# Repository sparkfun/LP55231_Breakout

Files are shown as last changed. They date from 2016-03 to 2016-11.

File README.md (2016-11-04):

SparkFun LP55231 LED Driver Breakout
========================================

SparkFun LP55231 LED Driver Breakout

[*SparkFun LP55231 LED Driver Breakout (BOB-13884)*](https://www.sparkfun.com/products/13884)

Breakout Board for the Texas Instruments LP55231 9-channel LED driver IC, with three onboard RGB LEDs.

Repository Contents
-------------------

* **/Documentation** - LP55231 data sheet.
* **/Enclosure** - Enclosure files
* **/Firmware** - Some test sketches.  For more useful sketches, please refer to the [LP55231 Arduino Library](https://github.com/sparkfun/SparkFun_LP55231_Arduino_Library)
* **/Hardware** - Eagle design files (.brd, .sch)
* **/Libraries** - work-in-progress libraries.  Release library has [its own repository](https://github.com/sparkfun/SparkFun_LP55231_Arduino_Library)
* **/Production** - Production panel files (.brd)
* **/Software** - Related software for the <PRODUCT NAME>

Documentation
--------------
* **[Library](https://github.com/sparkfun/SparkFun_LP55231_Arduino_Library)** - Arduino library for the LP55231 breakout board.
* **[Hookup Guide](https://learn.sparkfun.com/tutorials/lp55231-breakout-board-hookup-guide)** - Basic hookup guide for the LP55231 breakout.
* **[SparkFun Fritzing repo](https://github.com/sparkfun/Fritzing_Parts)** - Fritzing diagrams for SparkFun products.
* **[SparkFun 3D Model repo](https://github.com/sparkfun/3D_Models)** - 3D models of SparkFun products.
* **[SparkFun Graphical Datasheets](https://github.com/sparkfun/Graphical_Datasheets)** -Graphical Datasheets for various SparkFun products.

Product Versions
----------------
* [BOB-13884](https://www.sparkfun.com/products/13884)- Storefront page where you can purchase the LP55231 breakout board.

Version History
---------------
* [7303a14bc03e4db13bc608a852c81e9e0ca2a5a7](https://github.com/sparkfun/LP55231_Breakout/commit/7303a14bc03e4db13bc608a852c81e9e0ca2a5a7) - Initial release version.

License Information
-------------------

This product is _**open source**_!

Please review the LICENSE.md file for license information.

If you have any questions or concerns on licensing, please contact techsupport@sparkfun.com.

Distributed as-is; no warranty is given.

- Your friends at SparkFun.

_<COLLABORATION CREDIT>_

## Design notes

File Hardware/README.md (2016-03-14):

SparkFun <PRODUCT NAME> Design Files
=====================================

The .sch and .brd files hare are Eagle CAD schematic and PCB design files from SparkFun Electronics.
A freeware version of Eagle can be found [here](http://www.cadsoftusa.com/download-eagle/freeware/).

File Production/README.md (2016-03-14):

SparkFun <PRODUCT NAME> Production Files
=========================================

These are the production files SparkFun uses for printing PCBs.

License Information
-------------------
This product is open source! 

The hardware is released under [Creative Commons ShareAlike 4.0 International](https://creativecommons.org/licenses/by-sa/4.0/).

Please use, reuse, and modify these files as you see fit. Please maintain attribution to SparkFun Electronics and release anything derivative under the same license.

Distributed as-is; no warranty is given.

- Your friends at SparkFun.

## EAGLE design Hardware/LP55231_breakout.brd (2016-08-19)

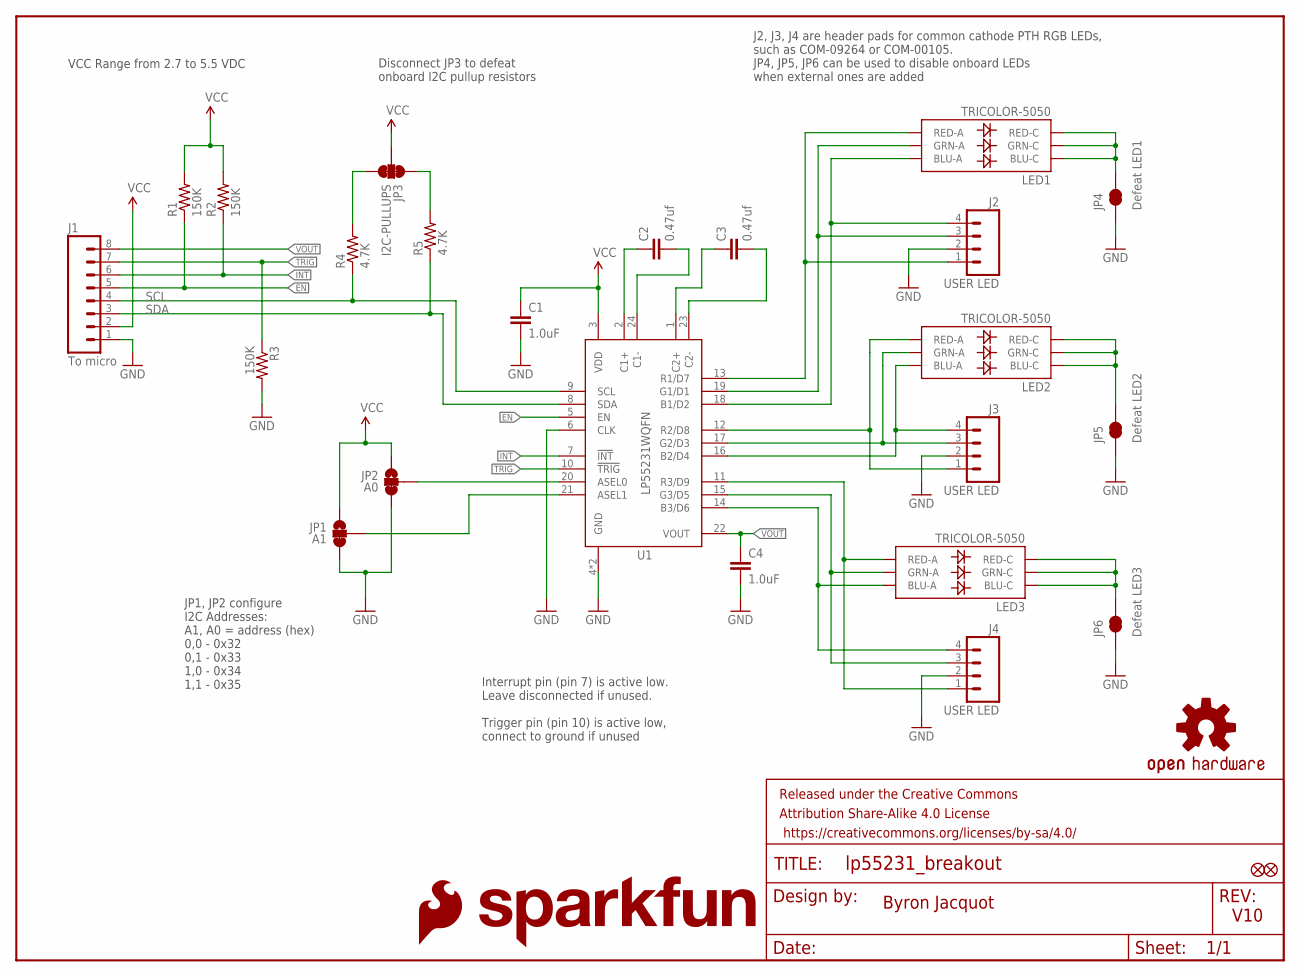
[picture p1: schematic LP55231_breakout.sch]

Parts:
C1, C4: 1.0uF; 0603-CAP
C2, C3: 0.47uf; 0603-CAP
FD1, FD2: FIDUCIALUFIDUCIAL; MICRO-FIDUCIAL
FRAME1: FRAME-LETTER; CREATIVE_COMMONS
J1: To micro; 1X08_NO_SILK
J2, J3, J4: USER LED; 1X04_NO_SILK_ALL_ROUND
JP1: A1; PAD-JUMPER-3-2OF3_NC_BY_TRACE_YES_SILK_FULL_BOX
JP2: A0; PAD-JUMPER-3-2OF3_NC_BY_TRACE_YES_SILK_FULL_BOX
JP3: I2C-PULLUPS; PAD-JUMPER-3-3OF3_NC_BY_TRACE_YES_SILK_FULL_BOX
JP4: Defeat LED1; PAD-JUMPER-2-NC_BY_TRACE_NO_SILK
JP5: Defeat LED2; PAD-JUMPER-2-NC_BY_TRACE_NO_SILK
JP6: Defeat LED3; PAD-JUMPER-2-NC_BY_TRACE_NO_SILK
LED1, LED2, LED3: TRICOLOR-5050; LED-TRICOLOR-5050
LOGO1: SFE_LOGO_FLAME.1_INCH; SFE_LOGO_FLAME_.1
LOGO2: SFE_LOGO_NAME.1_INCH; SFE_LOGO_NAME_.1
LOGO3: OSHW-LOGOS; OSHW-LOGO-S
R1, R2, R3: 150K; 0603-RES
R4, R5: 4.7K; 0603-RES
U1: LP55231WQFN; WQFN-24

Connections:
ADDR0: JP2.2, U1.20 (ASEL0)
ADDR1: JP1.2, U1.21 (ASEL1)
B1: J2.4, LED1.3 (BLU-A), U1.18 (B1/D2)
B2: J3.4, LED2.3 (BLU-A), U1.16 (B2/D4)
B3: J4.4, LED3.3 (BLU-A), U1.14 (B3/D6)
EN: J1.5, R1.1, U1.5 (EN)
G1: J2.3, LED1.1 (GRN-A), U1.19 (G1/D1)
G2: J3.3, LED2.1 (GRN-A), U1.17 (G2/D3)
G3: J4.3, LED3.1 (GRN-A), U1.15 (G3/D5)
GND: C1.2, C4.2, J1.1, J2.2, J3.2, J4.2, JP1.3, JP2.3, JP4.1, JP5.1, JP6.1, R3.2, U1.4 (GND), U1.6 (CLK), U1.EP (GND)
INT: J1.6, R2.1, U1.7 (!INT)
unnamed: JP6.2, LED3.4 (BLU-C), LED3.5 (RED-C), LED3.6 (GRN-C)
unnamed: JP5.2, LED2.4 (BLU-C), LED2.5 (RED-C), LED2.6 (GRN-C)
unnamed: JP4.2, LED1.4 (BLU-C), LED1.5 (RED-C), LED1.6 (GRN-C)
unnamed: C2.1, U1.2 (C1+)
unnamed: C2.2, U1.24 (C1-)
unnamed: C3.1, U1.1 (C2+)
unnamed: C3.2, U1.23 (C2-)
unnamed: JP3.1, R5.2
unnamed: JP3.3, R4.2
R1: J2.1, LED1.2 (RED-A), U1.13 (R1/D7)
R2: J3.1, LED2.2 (RED-A), U1.12 (R2/D8)
R3: J4.1, LED3.2 (RED-A), U1.11 (R3/D9)
SCL: J1.4, R4.1, U1.9 (SCL)
SDA: J1.3, R5.1, U1.8 (SDA)
TRIG: J1.7, R3.1, U1.10 (!TRIG)
VCC: C1.1, J1.2, JP1.1, JP2.1, JP3.2, R1.2, R2.2, U1.3 (VDD)
VOUT: C4.1, J1.8, U1.22 (VOUT)

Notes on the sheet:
Byron Jacquot
V10
VCC Range from 2.7 to 5.5 VDC
JP1, JP2 configure I2C Addresses: A1, A0 = address (hex) 0,0 - 0x32 0,1 - 0x33 1,0 - 0x34 1,1 - 0x35
J2, J3, J4 are header pads for common cathode PTH RGB LEDs, such as COM-09264 or COM-00105. JP4, JP5, JP6 can be used to disable onboard LEDs when external ones are added
Disconnect JP3 to defeat onboard I2C pullup resistors
Interrupt pin (pin 7) is active low. Leave disconnected if unused. Trigger pin (pin 10) is active low, connect to ground if unused

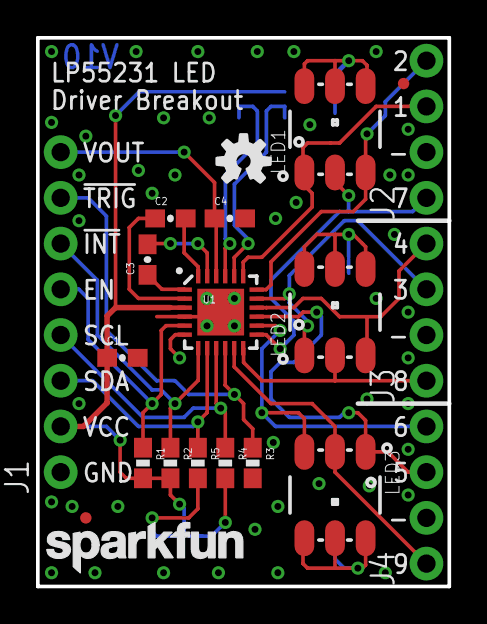
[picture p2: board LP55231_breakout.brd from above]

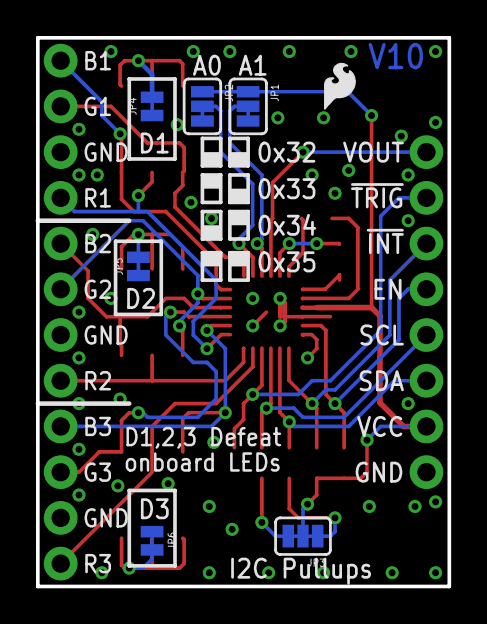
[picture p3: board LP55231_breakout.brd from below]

Board: 4 copper layers, 22.9 x 30.5 mm, 29 parts (7 on the bottom side), 28 nets.

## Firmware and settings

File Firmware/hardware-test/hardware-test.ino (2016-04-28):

#include <Wire.h>

static const int32_t enable_pin = 15; // Apparently active high?
static const int32_t trigger_pin = 14; // low if unused

// register stuff
static const uint8_t REG_CNTRL1 = 0x00;
static const uint8_t REG_CNTRL2 = 0x01;
static const uint8_t REG_RATIO_MSB = 0x02;
static const uint8_t REG_RATIO_LSB = 0x03;
static const uint8_t REG_OUTPUT_ONOFF_MSB = 0x04;
static const uint8_t REG_OUTPUT_ONOFF_LSB = 0x05;

// Per LED control channels - fader channel assig, log dimming enable, temperature compensation
static const uint8_t REG_D1_CTRL = 0x06;
static const uint8_t REG_D2_CTRL = 0x07;
static const uint8_t REG_D3_CTRL = 0x08;
static const uint8_t REG_D4_CTRL = 0x09;
static const uint8_t REG_D5_CTRL = 0x0a;
static const uint8_t REG_D6_CTRL = 0x0b;
static const uint8_t REG_D7_CTRL = 0x0c;
static const uint8_t REG_D8_CTRL = 0x0d;
static const uint8_t REG_D9_CTRL = 0x0e;

// Direct PWM control registers
static const uint8_t REG_D1_PWM  = 0x16;
static const uint8_t REG_D2_PWM  = 0x17;
static const uint8_t REG_D3_PWM  = 0x18;
static const uint8_t REG_D4_PWM  = 0x19;
static const uint8_t REG_D5_PWM  = 0x1a;
static const uint8_t REG_D6_PWM  = 0x1b;
static const uint8_t REG_D7_PWM  = 0x1c;
static const uint8_t REG_D8_PWM  = 0x1d;
static const uint8_t REG_D9_PWM  = 0x1e;

// Drive cuttent registers
static const uint8_t REG_D1_I_CTL = 0x26;
static const uint8_t REG_D2_I_CTL  = 0x27;
static const uint8_t REG_D3_I_CTL  = 0x28;
static const uint8_t REG_D4_I_CTL  = 0x29;
static const uint8_t REG_D5_I_CTL  = 0x2a;
static const uint8_t REG_D6_I_CTL  = 0x2b;
static const uint8_t REG_D7_I_CTL  = 0x2c;
static const uint8_t REG_D8_I_CTL  = 0x2d;
static const uint8_t REG_D9_I_CTL  = 0x2e;

static const uint8_t REG_MISC     = 0x36;
static const uint8_t REG_PC1 = 0x37;
static const uint8_t REG_PC2 = 0x38;
static const uint8_t REG_PC3 = 0x39;
static const uint8_t REG_STATUS_IRQ = 0x3A;
static const uint8_t REG_RESET      = 0x3D;

static const uint8_t REG_PROG1_START = 0x4C;
static const uint8_t REG_PROG2_START = 0x4D;
static const uint8_t REG_PROG3_START = 0x4E;
static const uint8_t REG_PROG_PAGE_SEL = 0x4f;

// Memory is more confusing - there are 4 pages, sel by addr 4f
static const uint8_t REG_PROG_MEM_BASE = 0x50;
//static const uint8_t REG_PROG_MEM_SIZE = 0x;//
static const uint8_t REG_PROG_MEM_END  = 0x6f;

static const uint8_t REG_ENG1_MAP_MSB = 0x70;
static const uint8_t REG_ENG1_MAP_LSB = 0x71;
static const uint8_t REG_ENG2_MAP_MSB = 0x72;
static const uint8_t REG_ENG2_MAP_LSB = 0x73;
static const uint8_t REG_ENG3_MAP_MSB = 0x74;
static const uint8_t REG_ENG3_MAP_LSB = 0x75;

static uint32_t next;
//static bool     ledon;

int8_t readReg(int8_t dev, int8_t reg)
{
  // Wire is awkward because it doesn't really have a register address concept.
  // http://www.arduino.cc/en/Tutorial/SFRRangerReader for reference
  
  Wire.beginTransmission(dev);
  Wire.write(reg);
  Wire.endTransmission();

  if(Wire.requestFrom(dev, 1))
  {
    return(Wire.read());
  }
  else
  {
    Serial.println("readReg failed?");
  }
}

void writeReg(int8_t dev, int8_t reg, int8_t val)
{
  Wire.beginTransmission(dev);
  Wire.write(reg);
  Wire.write(val);
  Wire.endTransmission();
}

void setup()
{
  
  pinMode(enable_pin, OUTPUT);
  digitalWrite(enable_pin, LOW);
  digitalWrite(enable_pin, HIGH);

  // Trigger is active hi, so unused means low
  pinMode(trigger_pin, OUTPUT);
  digitalWrite(trigger_pin, LOW);

  Wire.begin();

  next = millis() + 3000;
}



void loop()
{
  int32_t result;
  int8_t  val;
  static uint32_t count = 0;
  
  if(millis() >= next)
  {
    Serial.print("#");
    Serial.println(count);

    if(count == 0)
    {  
      // enable chip
//      writeReg(0x32, REG_CNTRL1, 0x40 );
//      val = readReg(0x32, REG_CNTRL1);
//      Serial.print("REG_CNTRL1 ");
//      Serial.println(val);

      // force reset
      writeReg(0x32, REG_RESET, 0xff);
      // reenable
      writeReg(0x32, REG_CNTRL1, 0x40 );
      
      val = readReg(0x32, REG_STATUS_IRQ);
      Serial.print("REG_STATUS_IRQ ");
      Serial.println(val);
      
      delay(100);

      val = readReg(0x32, REG_STATUS_IRQ);
      Serial.print("REG_STATUS_IRQ ");
      Serial.println(val);

      // enable internal clock & charge pump
      writeReg(0x32, REG_MISC, 0x1b);
      //writeReg(0x32, REG_MISC, 0x03);
      val = readReg(0x32, REG_MISC);
      Serial.print("REG_MISC ");
      Serial.println(val);

      // enable ratiometric color?
//      writeReg(0x32, REG_RATIO_MSB, 0x01);
//      writeReg(0x32, REG_RATIO_LSB, 0xff);

#if 1 
      // set all outputs to log
      writeReg(0x32, REG_D1_CTRL, 20);
      writeReg(0x32, REG_D2_CTRL, 20);
      writeReg(0x32, REG_D3_CTRL, 20);
      writeReg(0x32, REG_D4_CTRL, 20);
      writeReg(0x32, REG_D5_CTRL, 20);
      writeReg(0x32, REG_D6_CTRL, 20);
      writeReg(0x32, REG_D7_CTRL, 20);
      writeReg(0x32, REG_D8_CTRL, 20);
      writeReg(0x32, REG_D9_CTRL, 20);
#endif


      //Try poking in a program
      //turn on ram access?
      // CNTRL1 has 0's in engine control - IE: hold mode
      writeReg(0x32, REG_CNTRL2, 0x10);

      // the wait to change modes
      do
      {
        val = readReg(0x32, REG_STATUS_IRQ) & 0x10; // engine busy bit
        Serial.print(".");
      }
      while(val);

      //try to write program from example
      // datasheet says MSB of each instruction is in earlier address
      // TBD: could optimize with a sequence of byte writes, using auto increment
      writeReg(0x32, REG_PROG_MEM_BASE     , 0x9c);// 0 output map start at addr _
      writeReg(0x32, REG_PROG_MEM_BASE +  1, 0x06);
      writeReg(0x32, REG_PROG_MEM_BASE +  2, 0x9c );// 1 output map - sel at addr 4
      writeReg(0x32, REG_PROG_MEM_BASE +  3, 0x8e);
      
      writeReg(0x32, REG_PROG_MEM_BASE +  4, 0x0e);// 2 ramp up
      writeReg(0x32, REG_PROG_MEM_BASE +  5, 0xff);
      writeReg(0x32, REG_PROG_MEM_BASE +  6, 0x0f);// 3 ramp dn
      writeReg(0x32, REG_PROG_MEM_BASE +  7, 0xff);
      writeReg(0x32, REG_PROG_MEM_BASE +  8, 0x9d);// 4 next map entry
      writeReg(0x32, REG_PROG_MEM_BASE +  9, 0x80);
      writeReg(0x32, REG_PROG_MEM_BASE +  10, 0xa0);// 5 loop
      writeReg(0x32, REG_PROG_MEM_BASE + 11, 0x02);

      writeReg(0x32, REG_PROG_MEM_BASE + 12, 0x00);// 6 mux data
      writeReg(0x32, REG_PROG_MEM_BASE + 13, 0x01);
      writeReg(0x32, REG_PROG_MEM_BASE + 14, 0x00);// 7 mux data
      writeReg(0x32, REG_PROG_MEM_BASE + 15, 0x02);
      writeReg(0x32, REG_PROG_MEM_BASE + 16, 0x00);// 8 mux data
      writeReg(0x32, REG_PROG_MEM_BASE + 17, 0x04);
      writeReg(0x32, REG_PROG_MEM_BASE + 18, 0x00);// 9 mux data
      writeReg(0x32, REG_PROG_MEM_BASE + 19, 0x08);
      writeReg(0x32, REG_PROG_MEM_BASE + 20, 0x00);// 10mux data
      writeReg(0x32, REG_PROG_MEM_BASE + 21, 0x10);
      writeReg(0x32, REG_PROG_MEM_BASE + 22, 0x00);// 11mux data
      writeReg(0x32, REG_PROG_MEM_BASE + 23, 0x20);
      writeReg(0x32, REG_PROG_MEM_BASE + 24, 0x00);// 12mux data
      writeReg(0x32, REG_PROG_MEM_BASE + 25, 0x40);
      writeReg(0x32, REG_PROG_MEM_BASE + 26, 0x00);// 13mux data
      writeReg(0x32, REG_PROG_MEM_BASE + 27, 0x80);
      writeReg(0x32, REG_PROG_MEM_BASE + 28, 0x01);// 14mux data
      writeReg(0x32, REG_PROG_MEM_BASE + 29, 0x00);

      // and that's amlost a full page...can we put more data in next page??

#if 0
      // check too see if it's there?
      Serial.print("prog peek ");
      Serial.println((readReg(0x32, REG_PROG_MEM_BASE) & 0xff), HEX);
      Serial.println((readReg(0x32, REG_PROG_MEM_BASE+1) & 0xff), HEX);
      Serial.println((readReg(0x32, REG_PROG_MEM_BASE+2) & 0xff), HEX);
      Serial.println((readReg(0x32, REG_PROG_MEM_BASE+3) & 0xff), HEX);
#endif

      // set the PC1
      writeReg(0x32, REG_PC1, 0);
        
      // tell engine how to execute the program...free/step, etc
      writeReg(0x32, REG_CNTRL1, 0x40 | 0x20 );

      // and start execution
      writeReg(0x32, REG_CNTRL2, 0x20);
      
    }

#if 0
    for(uint8_t i = 0; i < 32; i++)
    {
      val = readReg(0x32, i);
      
      Serial.print("Register: ");
      Serial.print( i );
      Serial.print(":");
      Serial.println((val&0x0ff), HEX);
    }

    for(uint8_t i = 0x26; i < 0x2f; i++)
    {
      val = readReg(0x32, i);
      
      Serial.print("Register: ");
      Serial.print( i );
      Serial.print(":");
      Serial.println((val&0x0ff), HEX);
    }
#endif

    val = readReg(0x32, REG_PC1);
    Serial.print("PC1 val ");
    Serial.println(val);
    val = readReg(0x32, REG_ENG1_MAP_LSB);
    Serial.print("map lsbs");
    Serial.println(val);


#if 0
    val = count & 0xff;
    writeReg(0x32, REG_D8_PWM, val );
    writeReg(0x32, REG_D3_PWM, val );
    writeReg(0x32, REG_D4_PWM, val );

    writeReg(0x32, REG_D9_PWM, 0xff-val );
    writeReg(0x32, REG_D5_PWM, 0xff-val );
    writeReg(0x32, REG_D6_PWM, 0xff-val );
//
//    writeReg(0x32, REG_D7_PWM, (count>>1) );
//    writeReg(0x32, REG_D1_PWM, count );
//    writeReg(0x32, REG_D2_PWM, count );


//    val = readReg(0x32, REG_D8_PWM);
//    Serial.print("PWM D8 val ");
//    Serial.println(val);

#endif
    next += 1000;
    count++;
  }
}

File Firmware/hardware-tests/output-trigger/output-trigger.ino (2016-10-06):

#include <lp55231.h>

#include <Wire.h>

//#include "lp55231.h"

static const int32_t enable_pin = 15; // Apparently active high?
static const int32_t trigger_pin = 14; // low if unused
static const int32_t interrupt_pin = 16;


static uint32_t next;
//static bool     ledon;

static lp55231 ledChip(0x32);

/*
 * More trickery at play here (not as tangled as the interrupt example).
 * 
 * The LP55231 trigger line can be used as both an input and an output.
 * This example does exactly that...bit at first,v we couldn't explain why it worked.
 * 
 * The Trigger instruction on the LP allows for it listen for a trigger, or to drive 
 * the trigger line.  If both options are used in the same instruction, it sends a 
 * short (roughly 100 uSec) trigger pulse, then waits for a response.
 * 
 * This sketch waits until it sees that pulse, observes it going high again, then 
 * drives the line.
 * 
 * But it wasn't entirely apparent why & how it was working.  The AVR port pin 
 * architecture held the explanation.
 * 
 * The trigger pin on the pro micro is configured as INPUT_PULLUP in
 * setup().  Loop polls that pin, looking for a low.  When it finds a low, it waits for 
 * it to go high again, waits a touch longer, the drives it low itself.
 * 
 * Yes, it's an input...but it's allowed to drive it low, but somewhat indirectly.
 * 
 * When configured as an output, the data bits enable the pullup resistors.
 * 
 * So by writing a low to the output pin, we essentially defeat the pullup.
 * The Trigger line is pulled low on the LP breakout, which takes over when the 
 * PUP is defeated.
 * 
 * This will probably work with other AVR based microcontrollers, but 
 * might not be portable beynd that.
 */

static const uint16_t program[] =
{
  0x9c09, // 0 map start addr
  0x9c8c, // 1 map end addr
  0x3000, // 2 wait
  0x0eff, // 3 ramp up over 255
  0x3000, // 4 wait
  0x0fff, // 5 ramp down over 255
  0x9d80, // 6 mux map next
  0xf040, // 7 trigger - send to micro, and wait for response.
  0xa002, // 8 loop to 2
  0x01ff, // 9 channel map - all
  0x01c0, // a channel map - reds
  0x0015, // b channel map - greens
  0x002a, // c channel map - blues
};


void setup()
{
  Serial.begin(9600);

  delay(2000);
  Serial.println("### Setup entry");

  pinMode(enable_pin, OUTPUT);
  digitalWrite(enable_pin, LOW);
  digitalWrite(enable_pin, HIGH);

  // Trigger is active hi, so unused means low
  // but External trigger signal is active low
  pinMode(trigger_pin, INPUT_PULLUP);
  //digitalWrite(trigger_pin, HIGH);

  pinMode(interrupt_pin, INPUT);

  ledChip.init();
  ledChip.reset();
  ledChip.enable();

  delay(1000);

  for (uint8_t i = 0; i < 9; i++)
  {
    ledChip.setLogBrightness(i);
    ledChip.setDriveCurrent(i, 111);
  }

#if 1
  if (ledChip.loadProgram(program, 16))
  {
    Serial.println("Program loaded?");
  }
  else
  {
    Serial.println("Program dodn't load?");
  }
#endif

  next = millis() + 3000;

  ledChip.clearInterrupt();
  
  ledChip.setEngineEntryPoint(0, 0);
  ledChip.setEnginePC(0, 0);
  
  ledChip.setEngineModeFree(0);
  ledChip.showControls();

  ledChip.setEngineRunning(0);

  Serial.println("### Setup complete");

}



void loop()
{
  int32_t result;
  int8_t  val;
  static uint32_t count = 1;

  if ( !digitalRead(trigger_pin))
  {
    Serial.println("trigger");

    while (!digitalRead(trigger_pin))
      ;

    delay(5);
    digitalWrite(trigger_pin, LOW);
    delay(5);
    digitalWrite(trigger_pin, HIGH);

  }

  if (millis() >= next)
  {
    Serial.print("#");
    Serial.print(count);

    Serial.print(" PC:");
    Serial.println(ledChip.getEnginePC(0));

    if (count == 1)
    {
      //ledChip.fastProgram(program);
    }

    //    if (count % 4 == 0)
    //    {
    //      Serial.println("send trigger");
    //      digitalWrite(trigger_pin, LOW);
    //      delay(20);
    //      digitalWrite(trigger_pin, HIGH);
    //
    //      Serial.println(ledChip.getEngineMap(0), HEX);
    //
    //    }

    count++;
    next += 1000;

  }
}

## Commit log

2016-03-15 Initial design files.
    Library, schem and PCB, all WIP.
    [LP55231_breakout.brd, LP55231_breakout.sch]
2016-03-24 PCB Work in progress.
    [LP55231_breakout.brd, LP55231_breakout.sch]
2016-03-25 Incremental PCB routing checkin.
    Eagle crashed and I'm paranoid now.
    [LP55231_breakout.brd, LP55231_breakout.sch]
2016-03-25 Routing approaching completion.
    [LP55231_breakout.brd, LP55231_breakout.sch]
2016-03-31 Prepping for review.
    BOM created, checklist scrubbed.
    [LP55231_breakout.brd, LP55231_breakout.sch]
2016-04-04 Straight out of QFN.
    Fewer bends & kinks.
    [LP55231_breakout.brd]
2016-04-04 Fixing review issues.
    -Fiducial moved from under silk.
    -Swapped numbering of LED's 2 & 3.
    [LP55231_breakout.brd, LP55231_breakout.sch]
2016-04-27 Adding a note for I2C r/w info.
2016-05-04 Incremental changes.
    Adding software library features to support hardware testing.
    Trigger and interrupt pins are working.
2016-05-06 Updates to PCB after testing.
    Preparing for second round of prototypes.
    [LP55231_breakout.brd, LP55231_breakout.sch]
2016-05-09 Updates after group review.
    Addressing things in issue #3:
    -bump version number
    -Add silk indicating flooded/empty configuration on A0/A1
    -space out passives on front (check tkeepout)
    -remove extra junction dot between 150k res and Vcc on schematic
    [LP55231_breakout.brd, LP55231_breakout.sch]
2016-05-10 Checklist updates for proto round 2.
    [LP55231_breakout.brd, LP55231_breakout.sch]
2016-05-11 Checklist review issues
    Numbering of jumpers vs. comments got mismatched.
    Now fixed.
    [LP55231_breakout.brd, LP55231_breakout.sch]
2016-06-15 Fixing RGB assignments of first LED.
    [LP55231_breakout.brd, LP55231_breakout.sch]
2016-06-21 Rolling version number
    From V02 to V03.
    [LP55231_breakout.brd, LP55231_breakout.sch]
2016-06-22 Changes post-review.
    "G" becomes "-", to prevent confusion with "6".
    Angle voliation inside LED pad remedied.
    [LP55231_breakout.brd]
2016-06-24 Clarifying one schematic note.
    [LP55231_breakout.sch]
2016-08-05 Adding micro->driver trigger example.
2016-08-16 Adding sketches for Interrupt and output triggering.
2016-08-16 Adding sample sketch example of bidirectional trigger.
    Got the pin direction question answered.
    There's an external pull down that tugs the line when the internal pulup
    gets defeated.
2016-08-17 Adding start on Arduino Library...
    Basics are working, but parallel engines, program verification are not.
2016-08-18 Program verification is working.
    On a single page, at least.
    Setting PC is still problematic.
    [parallel-engines.ino]
2016-08-19 Making updates after group & checklist reviews.
    Rolling version # to V10.
    [LP55231_breakout.brd, LP55231_breakout.sch]
2016-08-23 More integration tests
    Temperature reading
    ADC for outputs and voltages.
2016-08-25 Adding auto-larson-scanner
    Found & fixed pervasive error in page programming.
    Added larson scanner with large mapping table.
    [larson-scanner.ino]
2016-10-06 Adding interrupt-to-GPO override example.

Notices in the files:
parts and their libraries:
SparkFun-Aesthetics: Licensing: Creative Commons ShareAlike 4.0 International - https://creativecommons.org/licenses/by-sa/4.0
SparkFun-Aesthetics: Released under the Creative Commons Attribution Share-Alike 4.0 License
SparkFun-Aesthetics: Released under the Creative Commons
